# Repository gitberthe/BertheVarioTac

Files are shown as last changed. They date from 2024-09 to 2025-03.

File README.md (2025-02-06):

# Projet BertheVarioTac ESP32-2432S028
Projet d'alti vario gps parapente tactile (avec gestion des TMA CTR..., et mode guidage sol pour randonnée).
- Compatible bluetooth / XCTrack si nécessaire.
- Code C++ Visual Studio/PlateformIO.
- Plateforme Espressif ESP32 Dev Module, 2.8inch ESP32-2432S028, Arduino, ESP32-WROOM-32,  (processeur LX6 32bits, bi-core 240mhz).


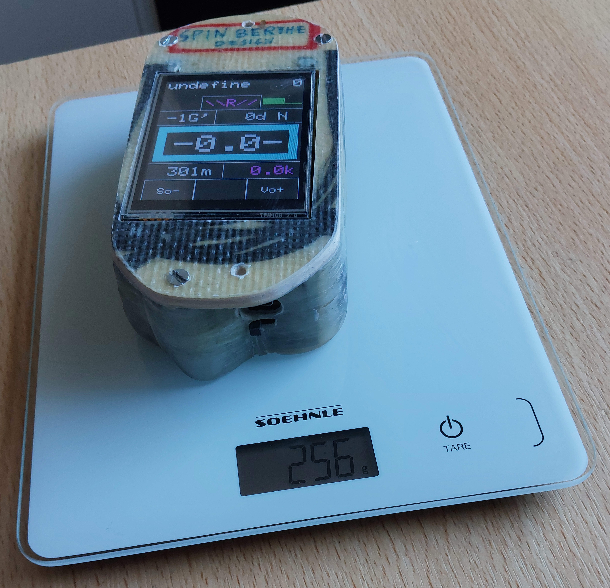
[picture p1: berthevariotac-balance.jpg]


**Utilisation / description :**
- documentation utilisateur et autre dans /documentation
- projet PlateformIO dans /BertheVarioTacPlatformIO
- editer/modifier avec codeblocks dans /Codeblocks
- documentation developpeur dans ../../DoxyBertheVarioTac avec le commande "doxygen Doxyfile.BertheVarioTac" depuis /Codeblocks

**Pour les développeur :**
- voir la documentation doxygen generée.

**Shemas dans /kicad-pcb :**

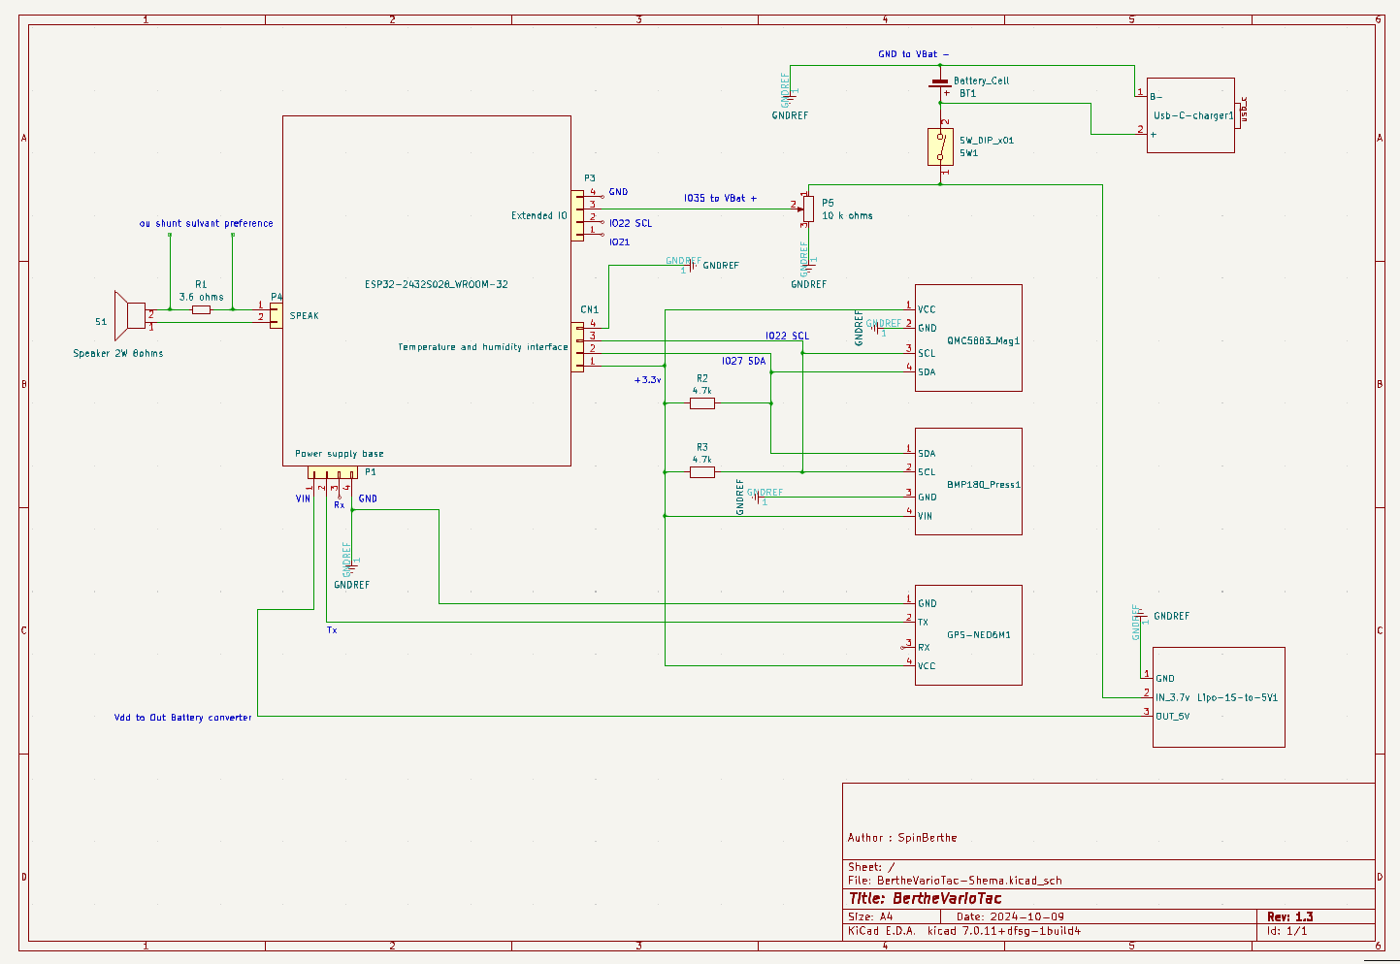
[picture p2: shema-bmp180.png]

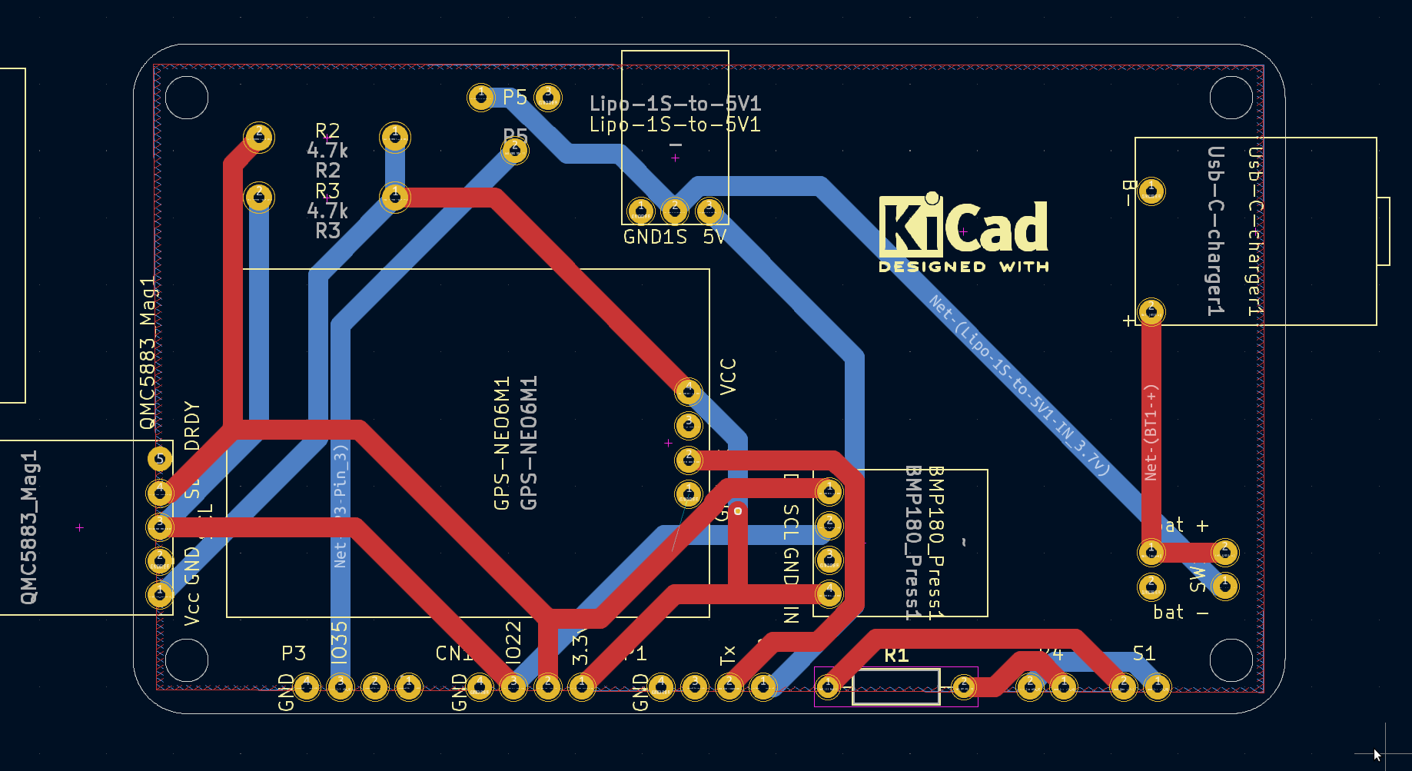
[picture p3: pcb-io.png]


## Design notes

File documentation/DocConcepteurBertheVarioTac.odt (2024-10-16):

Documentation Concepteur BertheVarioTac

Projet d’alti vario gps parapente

à base de 2.8inch ESP32-2432S028

Version : 2024091016b

https://github.com/gitberthe/BertheVarioTac

Compilé avec Visual Studio Code / PlatformIO

Espressif Systems

ESP32 Dev Module

ESP32-2432S028 Arduino

Wroom 32

langage C++.

# Mise en place de l’environnement logiciel :

Le logiciel est compilé avec Visual Studio Code / PlatformIO. Après l’ouverture du projet et téléchargement automatique des librairies, il faut décompresser 2.8inch_ESP32-2432S028R.rar.

* Copier alors le fichier 2.8inch_ESP32-2432S028R/1-Demo/Demo_Arduino/7_1_Touch_button_ILI9341_LovyanGFX/TFT_eSPI bottom layer replacement file/User_Setup.h ou ./src/Screen/User_Setup.h dans BertheVarioTacPlatformIO/.pio/libdeps/esp32dev/TFT_eSPI/User_Setup.h.

* De même, il faut copier BertheVarioTacPlatformIO/.pio/libdeps/esp32dev/LovyanGFX/examples/Advanced/LVGL_PlatformIO/src/lv_conf.h dans ./src/Screen/lv_conf.h

* La librairie pour le gestionnaire de fichier Wifi doit etre modifiée.

Dans BertheVarioTacPlatformIO/.pio/libdeps/esp32dev/ESP32 File Manager for Generation Klick ESPFMfGK/src/ESPFMfGKGa.cpp" ligne 6 : crc32.h => CRC32.h

La compilation du logiciel peut alors s’effectuer.

# Calibration de l’écran :

Il faut obtenir 8 paramètres de calibration de l’écran. Pour cela dans src/Screen/CLGFX.cpp dé-commenter la portion adéquate dans CLGFX::InitScreen() (ligne 81) pour récupérer sur le port série de PlatformIO les 8 paramètres à recopier par la suite dans le tableau de calibration calData[] (ligne 78). On a ainsi les bonnes coordonnées XY d’un point appuyé.

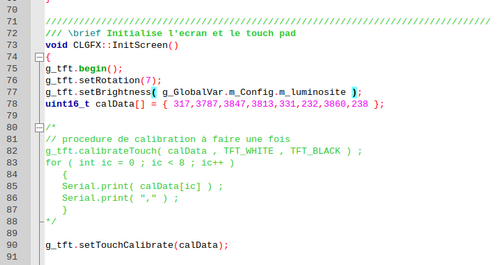
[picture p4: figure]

A noter que l’éclairage de l’écran perturbe grandement la mesure de luminosité (à isoler donc).

# Connexion Gps GY-NEO6MV2 :

If faut alimenter correctement le module par le connecteur CN1 en 3,3v. De même connecter la broche Tx du gps à la broche Tx du connecteur P1.

(la broche la broche IO35 du connecteur P3 est ainsi libre).

Attention, l’utilisation du Gps peut poser problème en mode débogage pour utiliser la liaison série usb de PlatformIO.

# Connexion capteur de pression BMP180 ou MS5611 :

If faut alimenter correctement le module par le connecteur CN1 en 3,3v. De même connecter la broche SDA à l’entrée 27 du connecteur CN1. Et la broche SCL à la pin 22 du connecteur P3 pour les ESP32-2432S028R ou à la broche NC/IO22 du connecteur CN1 pour les ESP32-2432S028.

# Connexion capteur magnétique QMC5883 :

If faut alimenter correctement le module par le connecteur CN1 en 3,3v. De même connecter la broche SDA à l’entrée 27 du connecteur CN1. Et la broche SCL à la pin 22 du connecteur P3 ou CN1. Capteur en parallèle sur le bus I2C avec le capteur de pression.

Ne pas oubliez de faire la calibration logicielle du capteur magnétique pour son bon fonctionnement (voir documentation utilisateur). Pour le boîtier, je vais essayer de mettre le câblage et le haut parleur le plus loin de ce capteur.

# Connexion de la batterie :

Connecter la batterie à la pin IO35 de la prise P3, par l’intermédiaire d’un potentiomètre de 10k ohms. Que l’on réglera pour avoir la bonne tension affichée.

# Alimentation :

Connecter la batterie 4,2v 1S lipo 2000 mah à la broche Vin de P1 par l’intermédiaire du convertisseur DC-DC 3,7v / 5V. Connecter la batterie au chargeur Usb C.

# haut parleur :

Connecter le haut parleur à la prise P4 par l’intermédiaire d’un résistance de votre choix ou un shunt pour un très fort volume (haut parleur 2W 8 ohms + résistance 3,6 ohms dans mon cas) .

# Utilisation du PCB :

Depuis la versions 20241010a un pcb est disponible. Connecter les différentes prises sur ce pcb. (prises JST 1.25) (à valider)

# Téléchargement du firmware :

Pour télécharger le firmware il y a 2 façons :

- soit par câble usb avec platformio ou un autre logiciel.

- soit par wifi. Il faut alors mettre le vario en mode téléchargement Fir en bas à droite de la page Sys. Et dé-commenter dans platformio.ini les lignes :

; extra_scripts = platformio_upload.py

; upload_protocol = custom

; upload_url = http://192.168.148.237

Avec bien sur l’adresse ip de l’url donnée par l’écran du BertheVarioTac. Cette procédure ne peut toutefois pas être faite au premier téléchargement de la carte ESP-2432S028 (R). Le logiciel ne s’y trouvant pas, il faut appliquer la procédure USB.

# Quelques photos :

Le câblage sur plaquette sans alimentation avec capteur MS5611 :

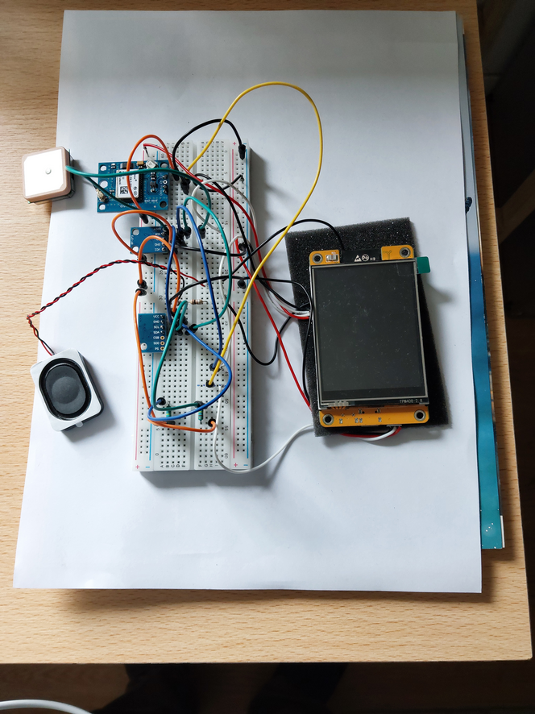
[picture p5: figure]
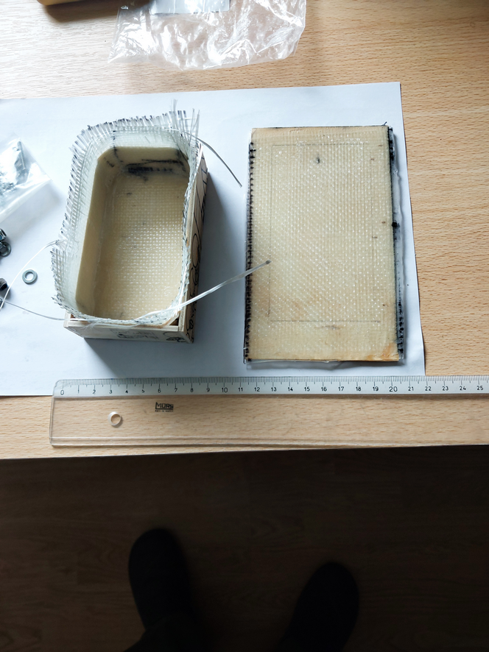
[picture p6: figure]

Les premiers pas du boîtier fibre époxy :

Les composants de la partie alimentation (testés sur la carte seule) :

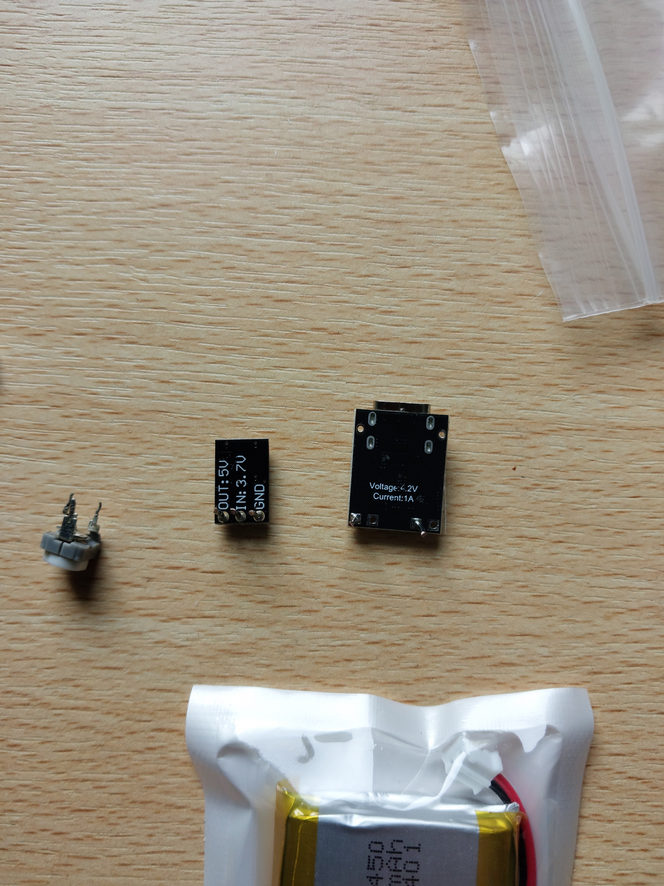
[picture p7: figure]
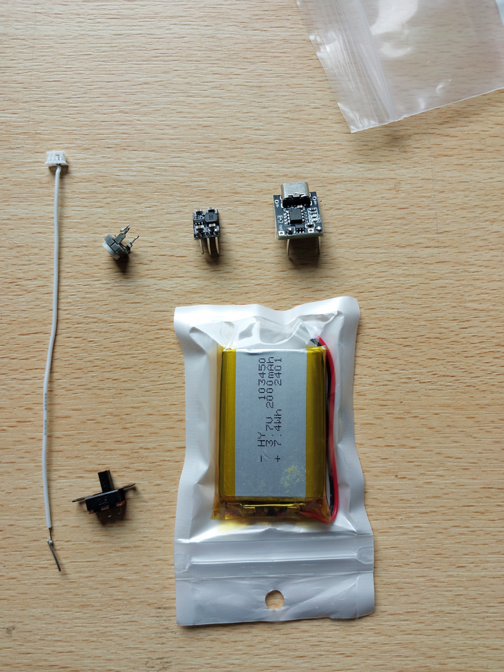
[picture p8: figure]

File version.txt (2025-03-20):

le 20250320a :
 - prise en compte de la hauteur sol pour pre-alarme frontiere XY à Saint-Sandoux.
 - emmission message xc_track determiné uniquement par #define XC_TRACK 
 - son vario toujours determiné par [xc_track] == 0 
 - declenchement debut de vol par 2 Vz minimales consecutives. 

le 20250301a :
 - meilleur prise en compte zone st-yan
 
le 20250225b :
 - modif plantage si mauvais zonesper.txt.

le 20250225a :
 - bug periodes tma st-yan. 

le 20250213a2 :
 - version documentation.

le 20250213a :
 - Modification de CZoneAer.
 - prise en compte de la hauteur sol pour la marge altitude zone à Corent.

le 20250210a :
   - ihm ligne vide si pas de zone TMA/CTR proche alti <=500m et dist <=999m.
   
le 20250209b :
 - remise a true des beep alarme zone, au debut du vol, lors desactivation
   attente gps.

le 20250209a :
 - apparition conditionnelle de l'altitude proche <500m et distance proche <= 999m.
   ex : _________ ou 455A _____ ou _____ 687NE ou 499A 999SE.
 - modification de CDistFront::IsNearFront().

le 20250208a :
 - alternance affichage terrain proche/finesse avec altitude/distance/cap 
   jusqu'a la prochaine zone TMA/CTR... rencontrée, à l'altitude ou l'on est,
   en metres. 999m maximum.
 - penetration zone TMA activement testeé à clermont. altitude/distance/cap zone 
   proche moin testé.

le 20250207c :
 - corection fuite memoire ~CZoneAer(). Meilleur fonctionnement fileManager.

le 20250207b :
 - correction bug important zone activable masquée par zone avec derogation.

le 20250207a :
 - gain memoire wifi ota bluetooth.
 - correction bug CDistFront::IsNearFront() vecteurs colineaire.

le 20250206a :
 - calcul penetration zone et terrain proche à 2hz.

le 20250204a :
 - menu deroulant mode rando.
 - ajout de #define XC_TRACK dans BertheVarioTac.h pour eviter une consommation memoire si inutilise.
 
le 20250203a :
 - modification initialisation hauteur sol zone protegée fonction de la denomination 
    (variable et plus 1000/500/300/150/50m ex: "PROTECT reserve annecy 200m/sol")

le 20250130a :
 - ajout de [xc_track] pour envoi de la pression par bluetooth à XC-Track.

le 20250129a :
 - platform https://github.com/tasmota/platform-espressif32/releases/download/2024.12.30/platform-espressif32.zip
 - CSoundSvr changé.

le 20250125c :
 - page tma dessous, enregistrement point gps dans fichier terconnu.txt.
 
le 20250125b :
 - gestion de la luminosite de l'ecran differente au sol.
 - [lum_seconde] à la place de [luminosite] dans fichier de config.

le 20250125a :
 - offset temperature a froid.
 - Modification tma activation/desactivation.

le 20250124c :
 - screen epd text.

le 20250124b :
 - ecran histo en minutes decimale.
 - alarme sonore reculade.
 - alarme sonore frontiere zone et limite altitude.
 - son zerotage.
 - [alarme_reculade] dans fichier de config.
 - zone protege mieux determine

le 20250124a :
 - correction pt-decollage menu rando
 - confirmation reboot info/rando.
 - [coef_filtre_alti_baro] à 0.85 par defaut.
 
le 20250123a2 :
 - mise a jour documentation utilisateur.

le 20250123a :
 - mode rando utilisable.
 
le 20250122c :
 - modification doc concepteur.
 - ebauche mode rando.

le 20250122b :
 - update de librairie.
 - ebauche mode rando.

le 20250122a :
 - ajout affichage tma hauteur sol pour zone protect.
 - mise en conformite/import BertheVario
  . tache gps
  . tache son
  . temps de vol en float
  . [vz_igc_ms] à 0,5 par défaut.
  . [vitesse_igc_kmh] à 14 par defaut.
  - modification GetAltiMetres(). Plus de reset m_DiffAltiFchAgl.

le 20250121a :
 - mise a jour doc concepteur.
 - ajout d'un fichier de modif BertheVario à importer dans BertheVarioTac.

le 20241209a :
 - CompZoneAerienne.exe windows 10, zonesaer.txt inchangé.

le 20241205a :
 - structuration CompZoneAerienne, zonesaer.txt inchangé.
 
le 20241204a :
 - bug zone meme nom dans CompZoneAerienne. zonesaer.txt nouveau.
 
le 20241203a :
 - Gain memoire nom de CZoneAer string => char*.
 
le 20241202c :
 - Gain memoire doublon nom de CZoneAer.
 
le 20241202b :
 - Modification buffer de points CZoneAer.
 
le 20241202a :
 - Modification affichage CompZoneAerienne.
 - Modification determination zone protegee CZoneAer.
 - [coef_filtre_alti_baro] à 0,9 par défaut.

le 20241201d :
 - resolution variable dans la compression de zone en short firmware.
   resolution entiere de 1 à 7 metres pour les zones en presence, 1.95metre en moyenne.

le 20241201c :
 - simplification calcul dans zone et modification fichier de validation zone.

le 20241201b :
 - calcul rayon maxi/resolution mini zone dans CompZoneAerienne.
 - Modification resolution compression zone à 10. metres.

le 20241201a2 :
 - bug ligne de commande vide CompZoneAerienne.
 
le 20241201a :
 - correction calcul erreur moyenne pour CompZoneAerienne.
 - CompZoneAerienne genere les zones à partir de terconnu.txt.
 - modification buffer calcul zone pour zone 1000 pts cevennes.
 - prise en compte hauteur sol zone protege 1000/500/300/150/50m.
 
le 20241130c :
 - correction calcul erreur moyenne pour CompZoneAerienne.
 
le 20241130b :
 - augmentation des decimales et precision dans zonesaer.txt.

le 20241130a :
 - Erreur moyenne des courbes pour CompZoneAerienne.

le 20241129b :
 - enfin beton sur CompZoneAerienne et zonesaer.txt. Compression
   iterative 3 points distance droite < 4.5m. 
 - la resolution firmware des zones reste à 18m.

le 20241129a :
 - essai algorithme CompZoneAerienne.
 - zonesaer.txt inchangé.
 - CompZoneAerienne.exe Windows 10.
 
le 20241128d :
 - reorganisation fichier/commentaires CompZoneAerienne.
 
le 20241128c :
 - modification CompZoneAerienne, reduction zone par droite proche 
   de nuage de points.
 
le 20241128b :
 - mise a jour documentation.

le 20241128a :
 - CompZoneAerienne.exe Windows 10 avec ses dll.
 
le 20241127a :
 - modification BVTZoneAerienne en CompZoneAerienne.
 - deplacement de CVecZoneReduce.h/cpp.
 - l'algorithme de CompZoneAerienne de reduction de zone est desormais la 
   distance à la droite < 7 metres, distance entre points < 40 metres et
   angle entre points < 5 degres.

le 20241126d :
 - ota en pointeur.

le 20241126c :
 - verification si compression lz4 efficace.
 
le 20241126b :
 - correction bug fuite memoire decompression zone.

le 20241126a :
 - modification dans Screen/lv_conf.h

le 20241125c2 :
 - modification doc utilisateur.

le 20241125c :
 - ajout de la compression des float 32 bit en short 16 bits pour les CZoneAer.
   Resolution de 18m et zone imperativement dans le cercle de rayon 589km (sinon reboot)
 - ajout de compression lz4 pour tableau des short 16bits de CZoneAer.

le 20241125b :
 - la creation du fichier de zone aeriennes se fait desormais avec BVTZoneAerienne.
 - la reduction du nombre de points de zone ce fait desormais dans BVTZoneAerienne.
 - dans BVTZoneAerienne 2 methodes de reduction de zone, par distance entre points
   de 50 metres, et angle plat de 6 degres.
 - format de zonesaer.txt inchangé.
 
le 20241125a :
 - modification Screen/lv_conf.h
 - modification CText2Screen
 - modification CDate
 
le 20241124a :
 - modification methode calcul Vz.
 - [sat_sec] à 12 par défaut.
 - [vitesse_igc_kmh] à 16 km/h par défaut.
 - [coef_filtre_alti_baro] à 0,8 par défaut.
 - suppression [periode_integration_sec].

le 20241121a :
 - pose d'une batterie 4000mah modele 965068.

le 20241101c :
 - modification ihm.

le 20241101b :
 - optimisation affichage page Vz.
 - bug ecran/carte sd.

le 20241101a :
 - vbat max 4.25v pour barregraphe autonomie.
 - grosse amelioration temps de reponse ihm à 10 hz et consommation CPU.
 
le 20241030c4 :
 - vbat max 4.3v pour barregraphe autonomie.

le 20241030c3 :
 - abaissement frequences calcul et affichage pour eco energie.
 - abaissement frequences scan serveur de son pour eco energie.

le 20241030c2 :
 - luminosite = 1 pour plein soleil.
 - seuil jaune 40% barregraphe tension batterie.

le 20241030c :
 - taille barregraphe batterie.
 - de init wifi.
 - mode economie d'ebergie

le 20241030b :
 - changement luminosite division.
 - barregraphe tension batterie.

 le 20241030a2 :
 - changement OTA.

le 20241030a :
 - changement luminosite minumum/maximum.
 
le 20241026a2 :
 - ajout procedure de reglage potentiometre dans documentation concepteur.

le 20241026a :
 - changement luminosite maximum.
 - pile CFinDeVol passe à 12 secondes.
 - [sat_sec] 12s par defaut pour 4 satellites.
 
le 20241025b2 :
 - changement de batterie pour une 4000mah 124065.

le 20241025b :
 - memorisation cap si non present.

le 20241025a :
 - ecartement du pcb batterie.

le 20241023b :
 - ajout vbatt en premiere page.
 - fonctionnement sur batterie ok (charge ok).

le 20241023a :
 - photos en plus dans documentation concepteur.

le 20241021a :
 - suppression fichier documentation obsolete.

le 20241020a :
 - [sat_sec] 0 pour 30 satellites.

 le 20241019a :
 - [sat_sec] 11s par defaut pour 4 satellites, 0 pour 28 satellites.
 
le 20241017a :
 - modification fonction luminosite.

le 20241016b :
 - optimisation memoire (suppression de taches et reduction buffer/stack).

le 20241016a :
 - correction bug ecran par mutex.
 - prise en compte du capteur de luminosite (à isoler des led de l'ecran).

le 20241015a :
 - [sat-sec] passe à 10s par defaut.

le 20241014a :
 - telechargement firmware par wifi ok.

le 20241012b :
 - validation capteur MS5611.

le 20241012a :
 - [temps_igc_sec] passe à 3s par defaut.
 - Vz declenclement de vol pendant [temps_igc_sec].
 - [sat_sec] 9s par defaut pour 4 satellites (puis 0s pour 26 satellites).
 - correction bug editeur cfg file.
 
le 20241010b :
 - essai mesure luminosite.

le 20241010a :
 - mise à jour documentation utilisateur et concepteur.
 - ajout numero de firmware en page sys.
 - pcb en commande.

le 20241009b :
 - ajout resistances Sda Scl pcb.

le 20241009a :
 - purge des boutons non bloquant.

le 20241008a :
 - [vz_igc_ms] pendant 3s pour déclenchement de vol.
 - modification pcb.

le 20241007b :
 - intergation logiciel pour capteur de pression MS5611 plus precis.

le 20241007a :
 - pcb a tester, compatible MS5611.

le 20241006a :
 - essai pcb.

le 20241005d :
 - modification conditions "EnVol".

le 20241005c :
 - doc utilisateur et modification code.
 
le 20241005b :
 - correction bug reboot systematique en wifi.

le 20241005a :
 - fonctionnement capteur magnetique ok.

le 20241003a :
 - fonctionnement gps + baro + son ok.

le 20241002a :
 - optimisation memoire globale;
 
le 20240928a :
 - correction bug zone limite alti XY

 le 20240927b :
 - modification zone limite alti XY

le 20240927a :
 - modification IHM zones hgt.

le 20240926a :
 - shema electrique kicad.
 - refonte ihm.

le 20240925c :
 - ihm selection de pages.

le 20240925b :
 - optimization int/long.
 
le 20240925a :
 - refonte calcul zones aeriennes.

le 20240924b :
le 20240924a :
 - modification IHM.

le 20240923c :
 - mesure de tension ok.

le 20240923a :
 - Wifi ok.
 
le 20240922b :
 - ok pages ihm sans bug carte SD.

le 20240921a :
 - trame gps fonctionnelle avec carte SD.
 
le 20240921a :
 - reorganisation CScreen

le 20240920a :
 - debut du projet BertheVarioTac

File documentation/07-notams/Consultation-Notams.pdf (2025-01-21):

# Site du Service de l’Information Aéronautique (SIA)

## Consultation des Notams

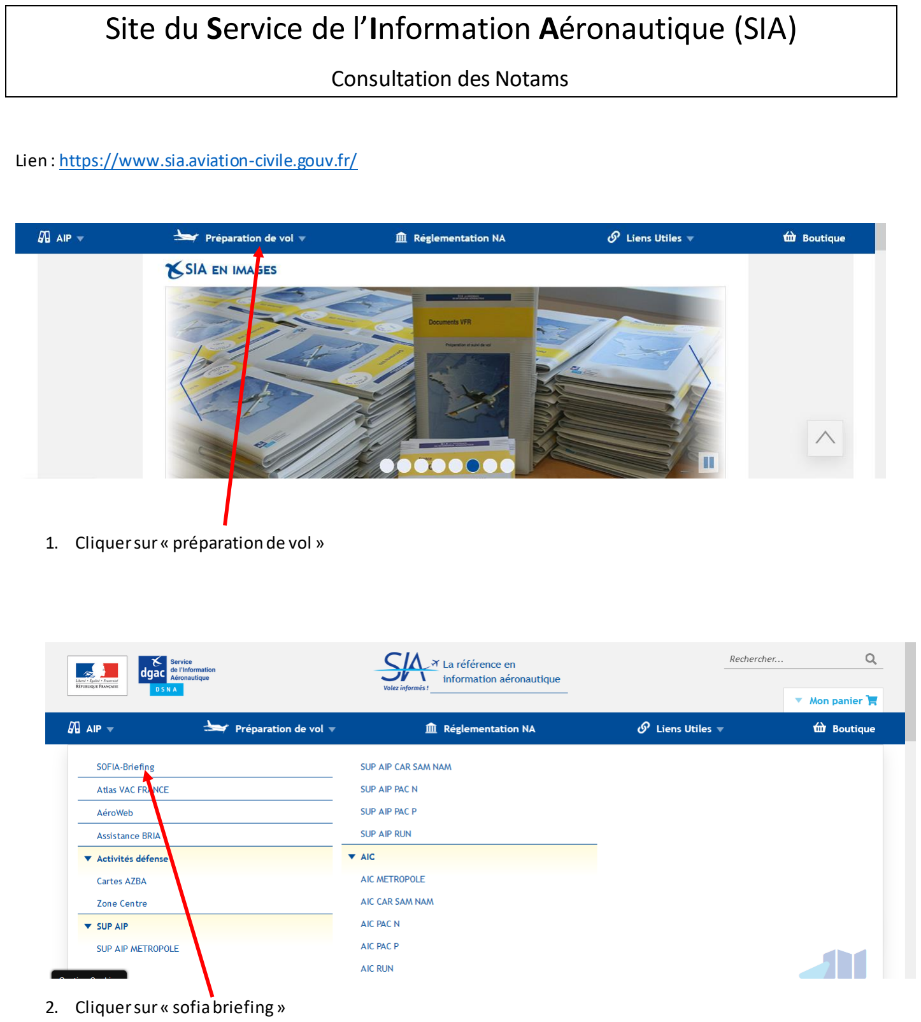
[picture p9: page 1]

Lien : https://www.sia.aviation-civile.gouv.fr/

1. Cliquer sur « préparation de vol »
2. Cliquer sur « sofiabriefing »

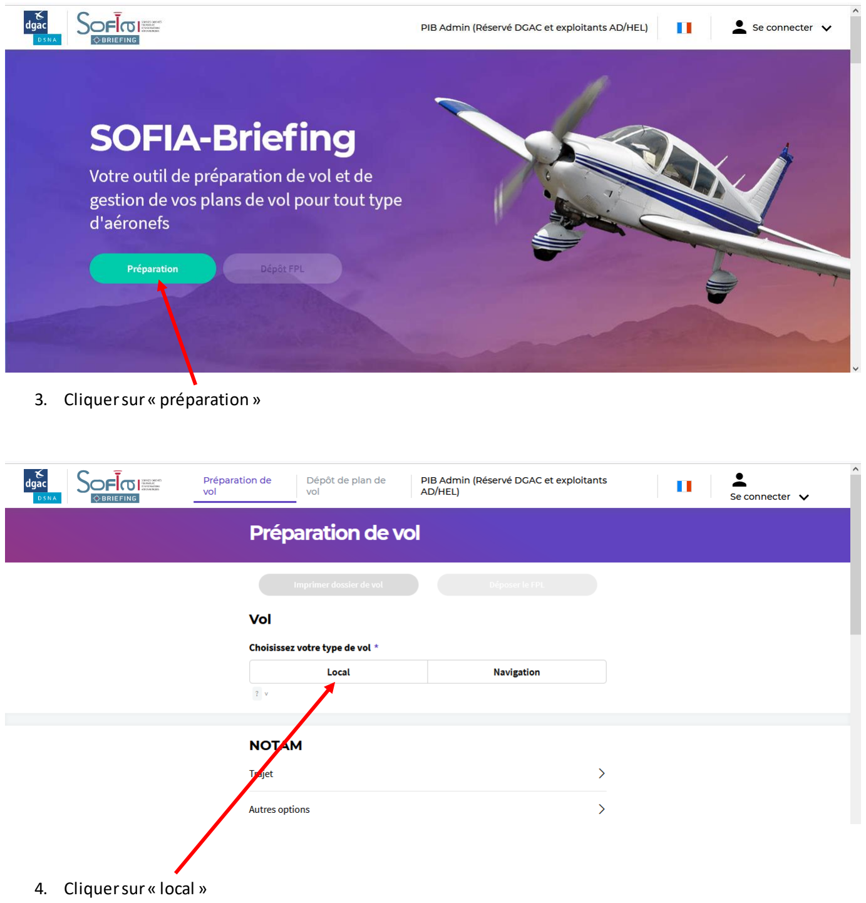
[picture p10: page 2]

3. Cliquer sur « préparation »
4. Cliquer sur « local »

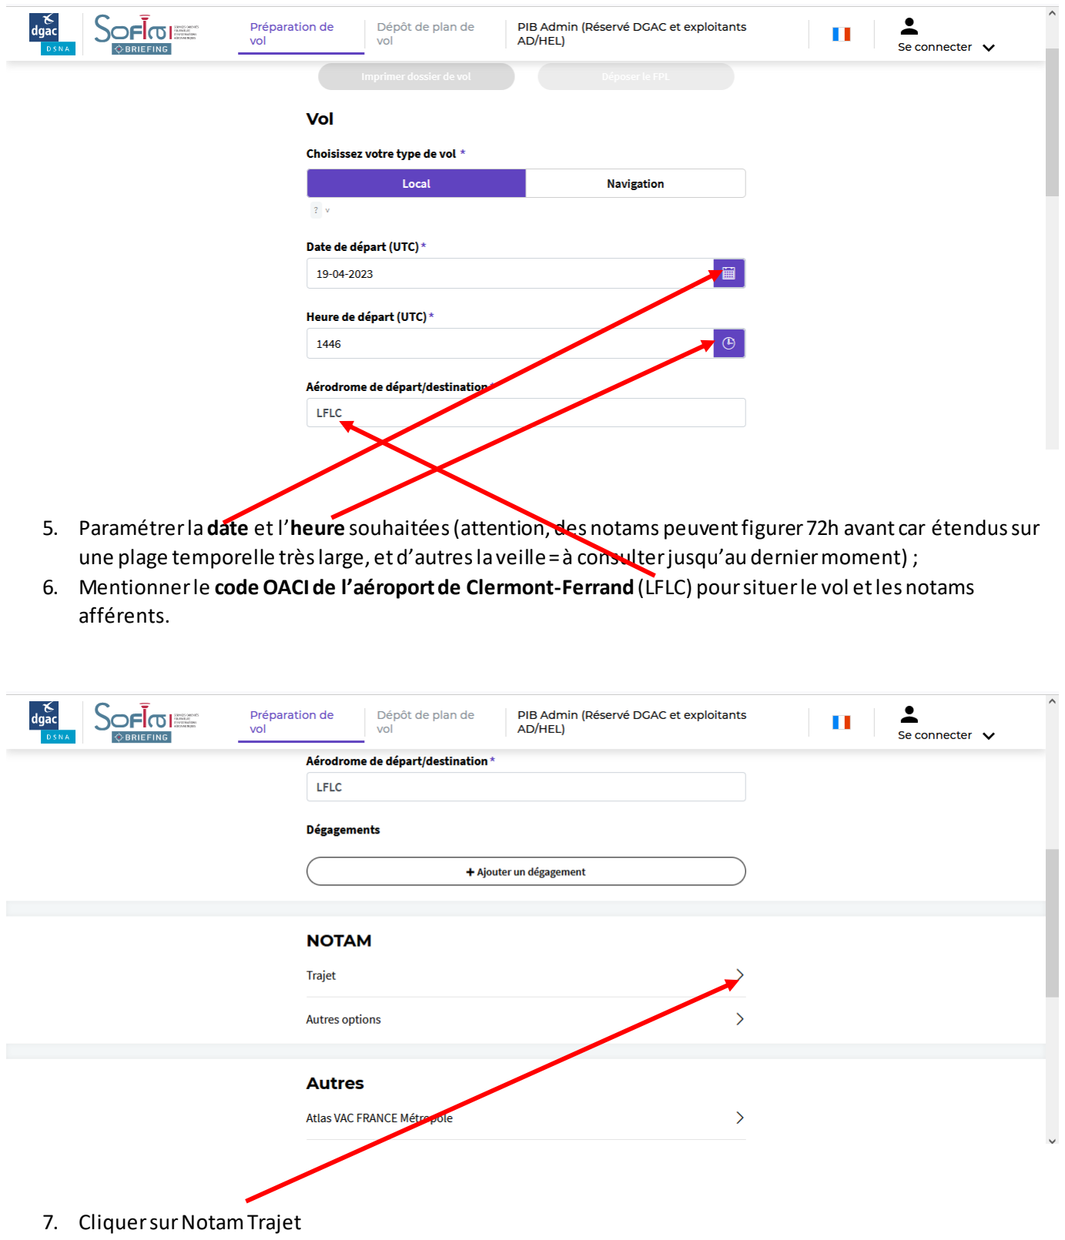
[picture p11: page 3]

5. Paramétrer la date et l’heure souhaitées(attention, des notams peuvent figurer 72h avant car étendus sur une plage temporelle très large, et d’autres la veille = à consulter jusqu’au dernier moment) ;
6. Mentionner le code OACI de l’aéroport de Clermont-Ferrand (LFLC) pour situer le vol et les notams afférents.
7. Cliquer sur Notam Trajet

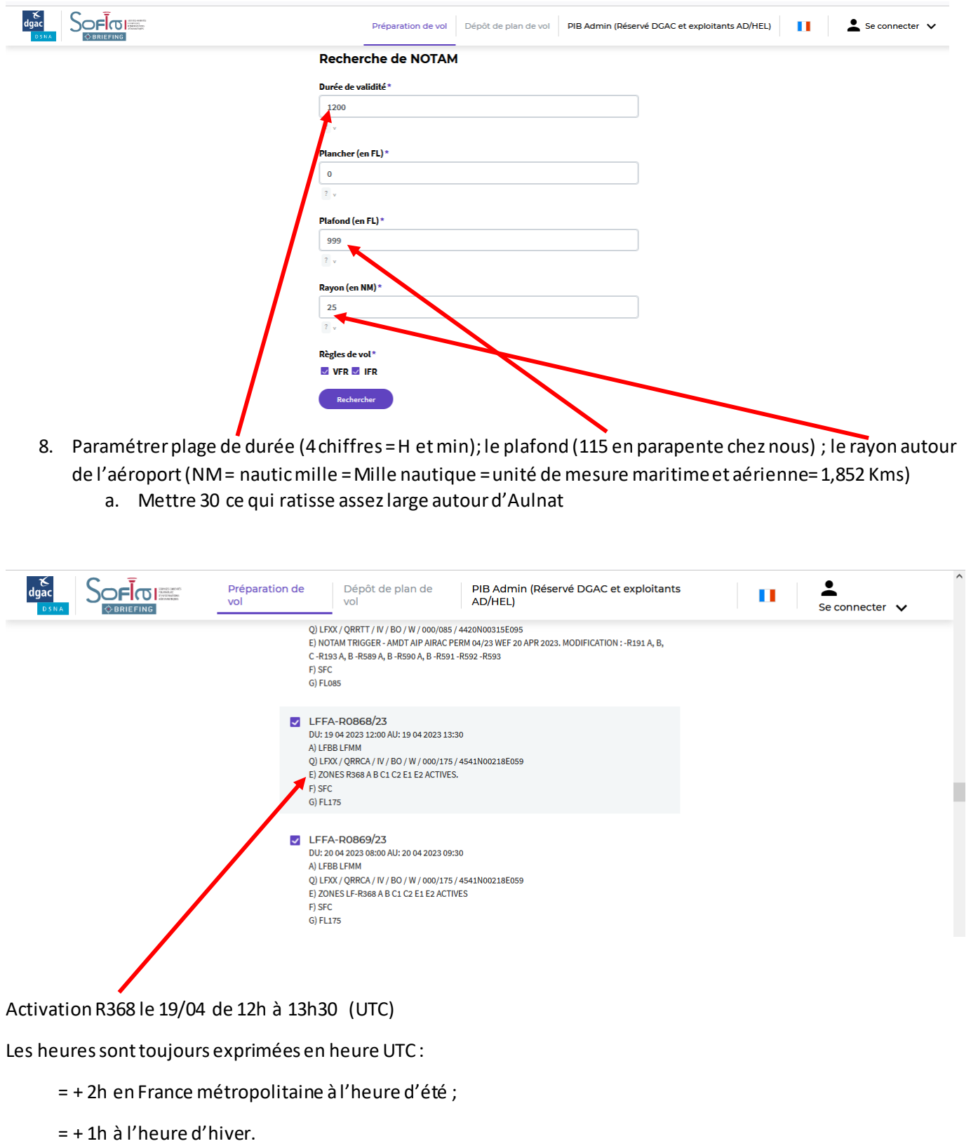
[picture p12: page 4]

8. Paramétrer plage de durée (4 chiffres = H et min); le plafond (115 en parapente chez nous) ; le rayon autour de l’aéroport(NM = nautic mille = Mille nautique = unité de mesure maritime et aérienne= 1,852 Kms)
a. Mettre 30 ce qui ratisse assez large autour d’Aulnat

Activation R368 le 19/04 de 12h à 13h30 (UTC)

Les heures sont toujours exprimées en heure UTC :

= + 2h en France métropolitaine à l’heure d’été ;

= + 1h à l’heure d’hiver.

## Décrypter un NOTAM

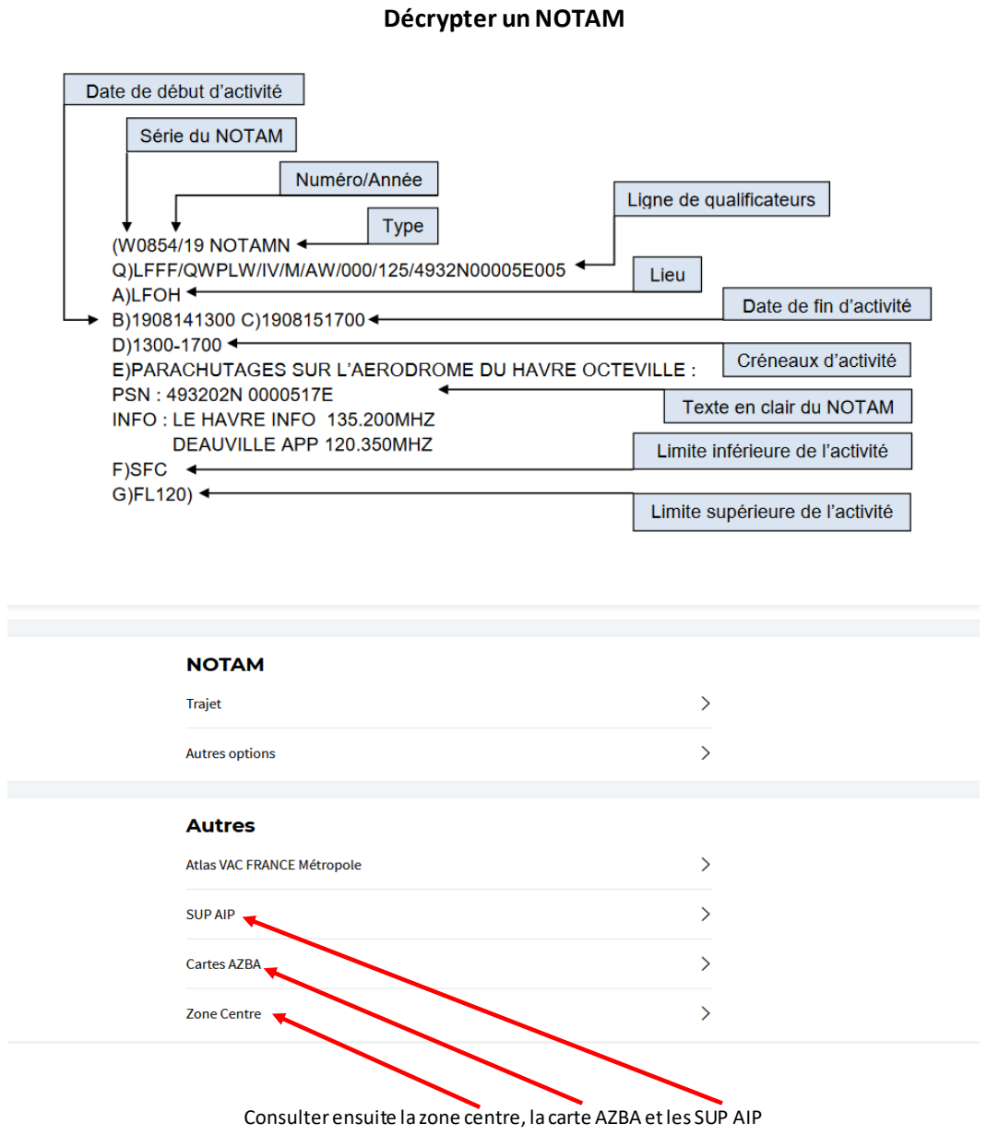
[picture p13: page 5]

Consulter ensuite la zone centre, la carte AZBA et les SUP AIP

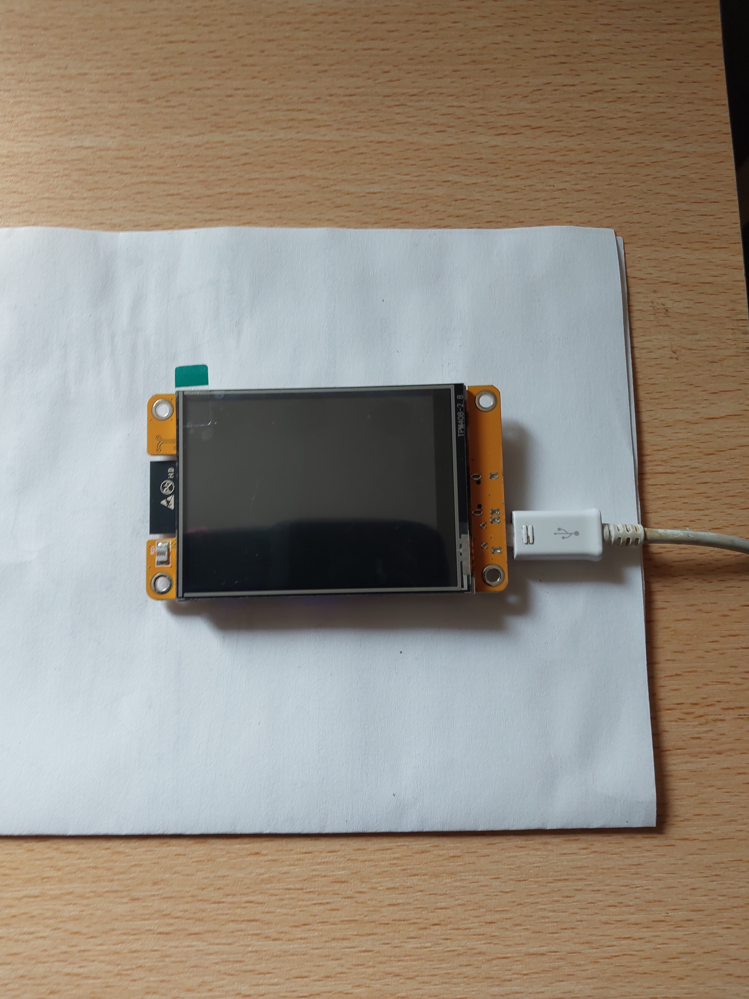
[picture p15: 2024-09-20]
ESP32-2432S028.jpg

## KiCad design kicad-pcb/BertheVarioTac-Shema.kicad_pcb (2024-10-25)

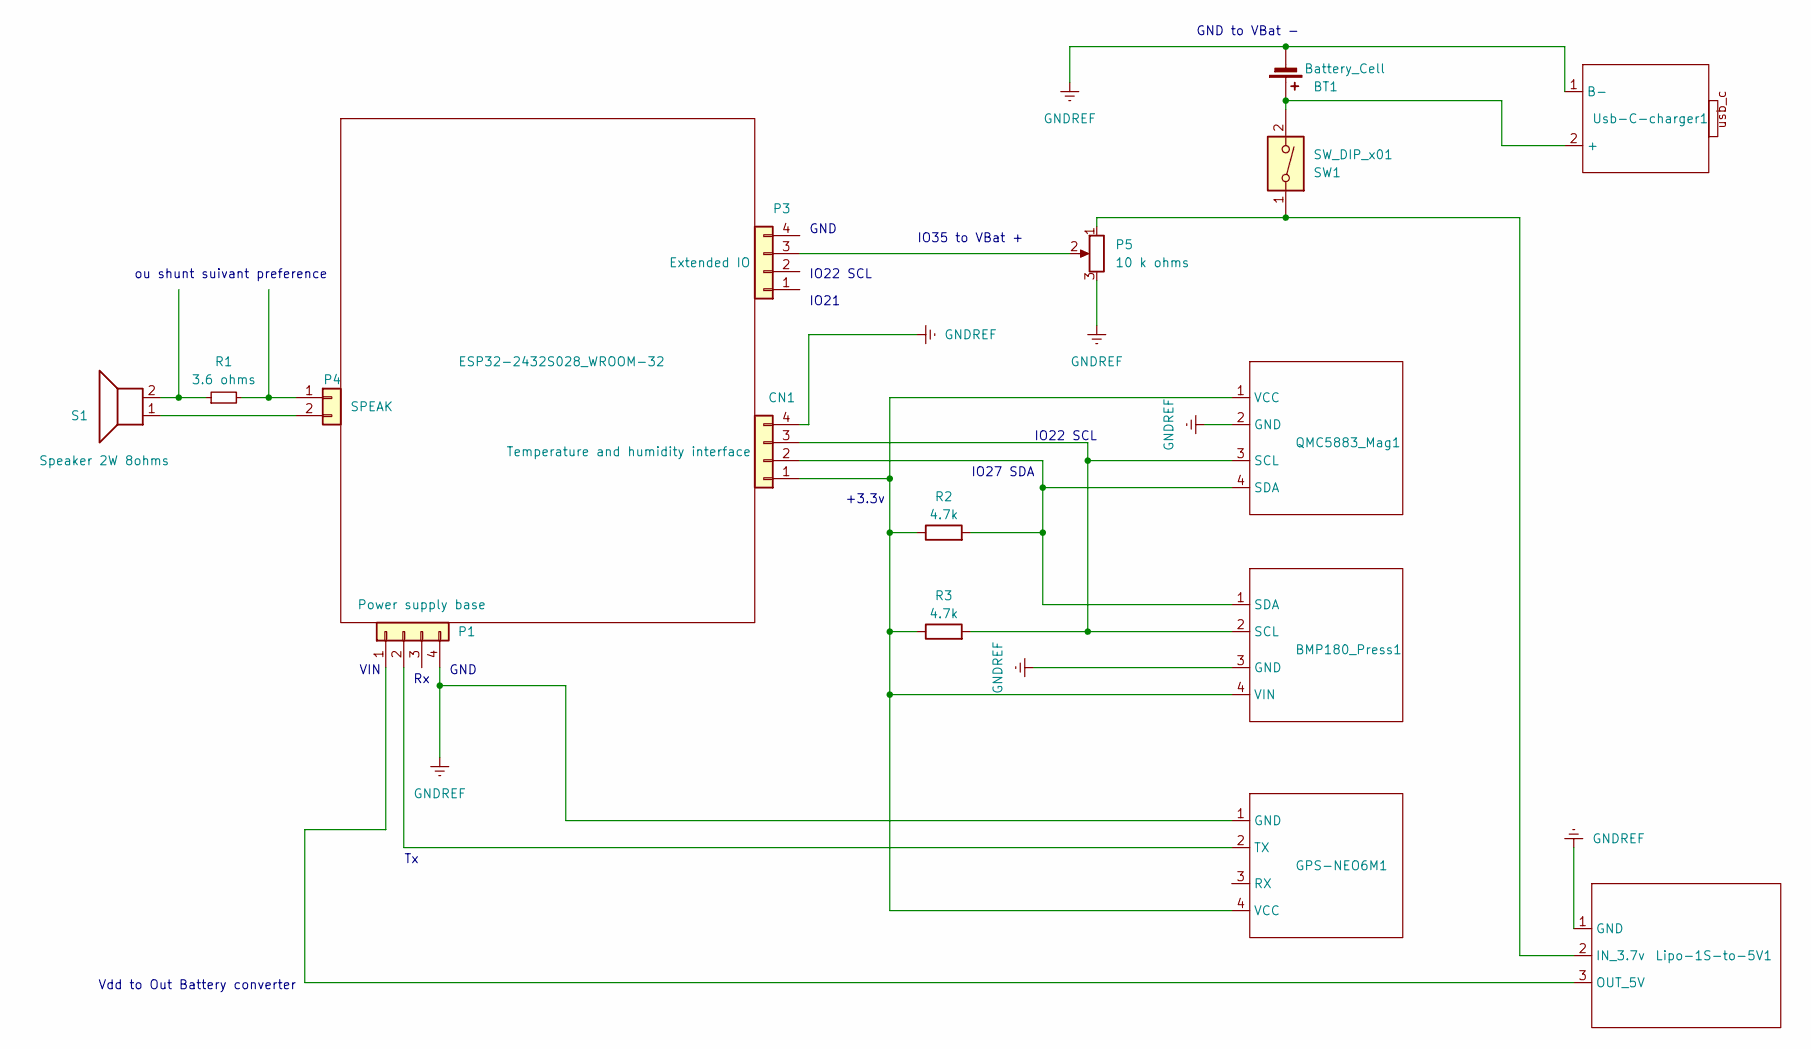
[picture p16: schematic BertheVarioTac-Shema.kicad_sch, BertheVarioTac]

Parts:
BMP180_Press1: BMP180
BT1: Battery_Cell; batterie
CN1: Temperature and humidity interface; 4 trous standard
ESP32-2432S028_WROOM-32: -; KiCad-Logo2_5mm_SilkScreen
GPS-NEO6M1: -; GPSNEO6V2
Lipo-1S-to-5V1: -; 1S-to-5v
P1: Power supply base; 4 trous standard
P3: Extended IO; 4 trous standard
P4: SPEAK; 2 trous standard
P5: 10 k ohms; potentiometre
QMC5883_Mag1: QMC5883
R1: 3.6 ohms; R_Axial_DIN0207_L6.3mm_D2.5mm_P10.16mm_Horizontal
R2, R3: 4.7k; R_47
S1: Speaker 2W 8ohms; 2 trous standard
SW1: SW_DIP_x01; 2 trous standard
Usb-C-charger1: -; Usb-C-Charger

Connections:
GNDREF: BMP180_Press1.3 (GND), BT1.2 (-), CN1.4, GPS-NEO6M1.1 (GND), Lipo-1S-to-5V1.1 (GND), P1.4, P5.3, QMC5883_Mag1.2 (GND), Usb-C-charger1.1 (B-)
unnamed: BMP180_Press1.2 (SCL), CN1.3, QMC5883_Mag1.3 (SCL), R3.2
unnamed: BMP180_Press1.1 (SDA), CN1.2, QMC5883_Mag1.4 (SDA), R2.2
unnamed: BMP180_Press1.4 (VIN), CN1.1, GPS-NEO6M1.4 (VCC), QMC5883_Mag1.1 (VCC), R2.1, R3.1
unnamed: BT1.1 (+), SW1.2, Usb-C-charger1.2 (+)
unnamed: GPS-NEO6M1.2 (TX), P1.2
unnamed: Lipo-1S-to-5V1.2 (IN_3.7v), P5.1, SW1.1
unnamed: Lipo-1S-to-5V1.3 (OUT_5V), P1.1
unnamed: P3.3, P5.2
unnamed: P4.1, R1.2
unnamed: P4.2, S1.1
unnamed: R1.1, S1.2

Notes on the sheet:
IO22 SCL
Vdd to Out Battery converter
GND
GND to VBat -
IO27 SDA
IO21
IO35 to VBat +
+3.3v
VIN
ou shunt suivant preference

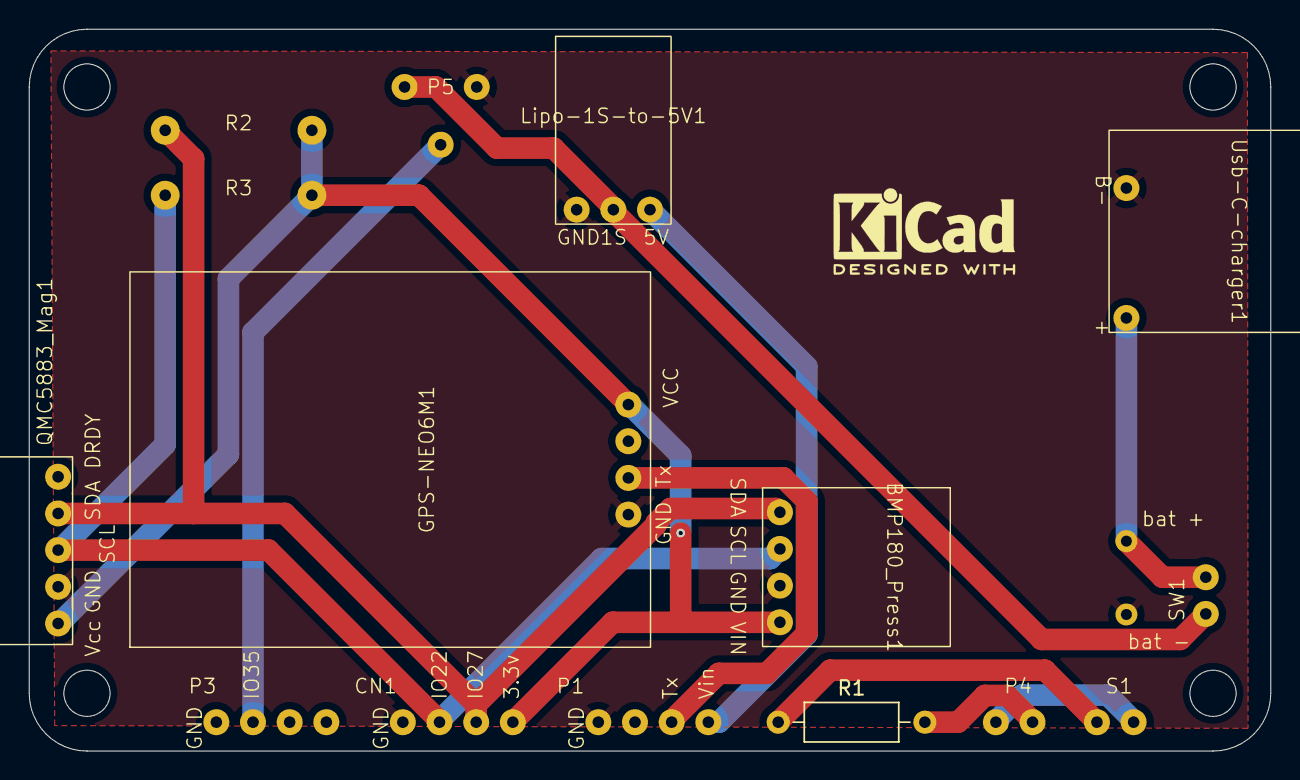
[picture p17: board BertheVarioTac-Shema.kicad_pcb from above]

Board: 2 copper layers, 86.0 x 50.0 mm, 17 parts (0 on the bottom side), 12 nets.

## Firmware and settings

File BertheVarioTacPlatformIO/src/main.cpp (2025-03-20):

////////////////////////////////////////////////////////////////////////////////
/// \file main.cpp
///
/// \brief loop de l'application
///
/// \date creation     : 21/09/2024
/// \date modification : 20/03/2025
///

#include "BertheVarioTac.h"

////////////////////////////////////////////////////////////////////////////////
/// \brief setup ESP32-2432S028
void setup()
{
//Serial.begin(115200);
#ifdef NO_GPS_DEBUG
 Serial.begin(9600);
 Serial.println("Debugage on" ) ;
#endif
//goto fin ;

// lancement tache son
g_GlobalVar.LanceTacheSound() ;
delay(500) ;
g_GlobalVar.BeepOk() ;
g_GlobalVar.beeper( SOUND_DELAY_ONLY , 100 ) ;
g_GlobalVar.BeepOk() ;

// tache de mise a jour % cpu
perfmon_start() ;

// init pin d'entree de tension
g_GlobalVar.InitBattery() ;

// initialisation de l'ecran tactile
g_tft.InitScreen() ;

// affaichage vbat
AfficheEcranDebut() ;

// init sdcard
g_GlobalVar.InitSDCard() ;

// Init BUS I2C
g_GlobalVar.InitI2C() ;

// lecture fichier terrains
g_GlobalVar.m_TerrainArr.LireFichierTerrains(TERRAIN_FCH) ;

// lecture fichier zones aeriennes
g_GlobalVar.m_ZonesAerAll.LectureFichiers() ;

// lecture fichier de configuration
g_GlobalVar.m_Config.LectureFichier() ;
g_GlobalVar.m_Config.FreeVect() ;

// init capteur de pression
g_GlobalVar.m_pCapteurPression->InitCapteur() ;

// init capteur magnetique
g_GlobalVar.m_QMC5883Mag.InitMagnetique() ;

#ifndef NO_GPS_DEBUG
 // init port serie GPS
 g_GlobalVar.InitGps() ;

 // lancement tache gps
 g_GlobalVar.LanceTacheGps(true) ;
#else
 g_GlobalVar.m_DureeVolMin = ATTENTE_MESSAGE_GPS ;
#endif // NO_GPS_DEBUG

// lancement tache beep
g_GlobalVar.LanceTacheVarioCapBeep() ;

// raz de l'ecran
g_GlobalVar.m_Screen.ScreenRaz(false) ;

// desactivation du wifi pour autonomie batterie
esp_wifi_stop() ;
esp_wifi_deinit() ;

// blue tooth
#ifdef XC_TRACK
 g_GlobalVar.m_BleXct.Init( BLE_NAME ) ;
#else
 esp_bt_controller_disable();
 esp_bt_controller_deinit();
#endif

// mode economie d'energie
esp_pm_config_esp32_t pm_config ;
pm_config.max_freq_mhz = 100; // 160 240
pm_config.min_freq_mhz = 40;
pm_config.light_sleep_enable = true ;
ESP_ERROR_CHECK(esp_pm_configure(&pm_config));
}


////////////////////////////////////////////////////////////////////////////////
/// \brief boucle sans fin
void loop()
{
// variables
static int count_10hz = 0 ;
static bool WifiSetupFileMgr = true ;
static bool WifiSetupOta = true ;

////////////////////////
// si mode wifi file mgr
if ( g_GlobalVar.m_ModeHttpFileMgr )
    {

    // si init wifi
    if ( WifiSetupFileMgr )
        {
        // init file manager
        WifiSetupFileMgr = false ;
        WifiInitFileMgr() ;
        }

    g_pfilemgr->handleClient();

    // si ecran pressé on reboot
    if ( !(count_10hz++%100) )
        {
        // traitement de touch pad
        g_GlobalVar.m_Screen.HandleTouchScreen() ;

        // scan les boutons tactiles
        g_GlobalVar.m_Screen.HandleButtons() ;

        if ( g_GlobalVar.m_Screen.IsCenterPressed() )
            g_GlobalVar.Reboot() ;
        }

    return ;
    }

////////////////////
// si mode wifi ota
if ( g_GlobalVar.m_ModeHttpOta )
    {
    // si init wifi
    if ( WifiSetupOta )
        {
        WifiSetupOta = false ;
        WifiInitOta() ;
        }

    WifiOtaHandle() ;

    // si ecran pressé on reboot
    if ( !(count_10hz++%100) )
        {
        // traitement de touch pad
        g_GlobalVar.m_Screen.HandleTouchScreen() ;

        // scan les boutons tactiles
        g_GlobalVar.m_Screen.HandleButtons() ;

        if ( g_GlobalVar.m_Screen.IsCenterPressed() )
            g_GlobalVar.Reboot() ;
        }

    return ;
    }

/////////////////
// ecran de debut
if( (millis()-g_GlobalVar.m_temps_debut)/1000 < 5 )
    {
    g_GlobalVar.m_Screen.m_MutexTft.PrendreMutex() ;
     AfficheEcranDebut() ;
    g_GlobalVar.m_Screen.m_MutexTft.RelacherMutex() ;
    delay( 1000 ) ;
    return ;
    }

////////
// 10 hz
unsigned long time = millis() ;

// traitement de touch pad
//g_GlobalVar.m_Screen.m_MutexTft.PrendreMutex() ;
 g_GlobalVar.m_Screen.HandleTouchScreen() ;
//g_GlobalVar.m_Screen.m_MutexTft.RelacherMutex() ;

// scan les boutons tactiles
g_GlobalVar.m_Screen.m_MutexTft.PrendreMutex() ;
 bool Action = g_GlobalVar.m_Screen.HandleButtons() ;
g_GlobalVar.m_Screen.m_MutexTft.RelacherMutex() ;

// affichage des boutons
g_GlobalVar.m_Screen.m_MutexTft.PrendreMutex() ;
g_tft.startWrite();
 g_GlobalVar.m_Screen.AfficheButtons() ;
g_tft.endWrite();
g_GlobalVar.m_Screen.m_MutexTft.RelacherMutex() ;

// compteur 10 hz
count_10hz++ ;

// 10 hz
while ( millis() - time < 100 )
    delay( 10 ) ;

// envoi bluetooth Xc-Track
#ifdef XC_TRACK
if ( g_GlobalVar.m_BleXct.IsInitialised() )
    g_GlobalVar.m_BleXct.Send() ;
#endif

///////
// 2 hz
if ( (count_10hz%5) && !Action )
    return ;

// si page Vz en cours
bool SpeedScreen = g_GlobalVar.m_Screen.GetEtatAuto() == CAutoPages::ECRAN_0_Vz ;

// affichage des pages
g_GlobalVar.m_Screen.m_MutexTft.PrendreMutex() ;
if ( SpeedScreen )
    g_tft.startWrite();
g_GlobalVar.m_Screen.SequencementPages() ;
if ( SpeedScreen )
    g_tft.endWrite();
g_GlobalVar.m_Screen.m_MutexTft.RelacherMutex() ;

// pour eviter mutex accet carte sd/ecran
if ( g_GlobalVar.m_Screen.GetEtatAuto() == CAutoPages::ECRAN_9b_RandoVolCarte )
    {
    CHgt2Agl Hgt2Agl ;
    g_GlobalVar.m_TerrainPosCur.m_AltiBaro = Hgt2Agl.GetGroundZ( g_GlobalVar.m_TerrainPosCur.m_Lon , g_GlobalVar.m_TerrainPosCur.m_Lat ) ;
    }

#ifdef NO_GPS_DEBUG
 static int count_debug = 0 ;
 Serial.print( count_debug++) ;
 Serial.println(" mode debug") ;
#endif


// calcul des zones aeriennes
g_GlobalVar.m_ZonesAerAll.CalcZone() ;

// calcul terrain le plus proche
g_GlobalVar.m_TerrainArr.CalcTerrainPlusProche() ;

// mode economie d'energie
//esp_light_sleep_start() ;

//tft.sleep() ;
//tft.powerSaveOn() ;
//g_tft.startWrite(); // bug avec carte SD si utilisation
//tft.beginTransaction();

// sequencement des pages
//g_GlobalVar.m_Screen.SequencementPages() ;

// raz de l'etat des boutons tactiles
//g_GlobalVar.m_Screen.RazButtons() ;

//g_tft.endWrite(); // bug avec carte SD si utilisation

//tft.clearClipRect()  ;
//tft.fillRect(0, 0,240,320,TFT_WHITE);
//tft.clearDisplay() ;
//tft.powerSaveOff() ;
//tft.wakeup() ;
//tft.endTransaction();

//uxTaskGetStackHighWaterMark(NULL) ;
}

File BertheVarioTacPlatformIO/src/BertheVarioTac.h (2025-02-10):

////////////////////////////////////////////////////////////////////////////////
/// \file BertheVarioTac.h
///
/// \brief Include global du projet de vario tactile
///
/// \date creation     : 20/09/2024
/// \date modification : 10/02/2025
///

//#define NO_OTA

//////////////////////
// includes globaux //
//////////////////////
#include <esp32-hal-i2c.h>
#include <esp32-hal-dac.h>
#include <Wire.h>
#include <Arduino.h>
#include <SPI.h>
#include <SD.h>
#include <WiFi.h>
#ifndef NO_OTA
 #include <WiFiClient.h>
 #include <WebServer.h>
 #include <HTTPClient.h>
 #include "esp_tls.h"
 #include "esp_http_client.h"
 #include "mbedtls/ssl.h"
 #include "ssl_client.h"
 #include "mqtt_client.h"
 #include "esp_tls.h"
 #include "esp_sntp.h"
#endif
#include <FS.h>
#include <ESPFMfGK.h>
#include <SFE_BMP180.h>
#include <MS5611.h>
#include <freertos/queue.h>
#include <soc/dac_channel.h>
#include <driver/dac.h>
#include <DFRobot_QMC5883.h>
#include <esp_wifi.h>
#include <esp_bt.h>
#include <esp_pm.h>
#include <lz4.h>
#include <NimBLEDevice.h>

#include <math.h>
#include <map>
#include <vector>
#include <algorithm>
#include <limits>

////////////////////////////////////////////////////////////////////////////////
// platform precedente
// bad : platform = espressif32
// bad : platform = https://github.com/pioarduino/platform-espressif32/releases/download/stable/platform-espressif32.zip
// bad : platform = https://github.com/platformio/platform-espressif32.git
// platform = https://github.com/tasmota/platform-espressif32/releases/download/2024.01.01/platform-espressif32.zip
// platform = https://github.com/tasmota/platform-espressif32/releases/download/2024.12.30/platform-espressif32.zip

//////////////////////////
// define pour le debug //
//////////////////////////
//#define GPS_DEBUG
//#define PERFMON_DEBUG
//#define NO_GPS_DEBUG
//#define MAG_DEBUG
//#define BRIGHT_DEBUG
//#define DEBUG_RANDO_VOL

/////////////////////////////
// define pour le materiel //
/////////////////////////////
//#define BMP180_PRESS
#define MS5611_PRESS
#define XC_TRACK

//////////////////////////
// includes du logiciel //
//////////////////////////
#include "GlobalVar/CMutex.h"
#include "Screen/CBrightness.h"
#include "Screen/CTouchButtons.h"
#include "Screen/CLGFX.h"
#include "Screen/CAutoPages.h"
#include "Screen/CText2Screen.h"
#include "Screen/CScreen.h"
#include "GlobalVar/CFileHistoVol.h"
#include "GlobalVar/CNbSatDelay.h"
#include "GlobalVar/CConfigFile.h"
#include "Calculateur/CSortArray.h"
#include "Calculateur/CTerrainsConnu.h"
#include "Calculateur/CFinSol.h"
#include "SDCard/CSDCard.h"
#include "Perfmon/esp32_perfmon.h"
#include "Geometrie/CVecteur2D.h"
#include "Geometrie/CDroite2D.h"
#include "Geometrie/CVecteur3D.h"
#include "Geometrie/CDroite3D.h"
#include "Geometrie/CMatrice3D.h"
#include "Geometrie/Segments.h"
#include "ZonesAeriennes/CDate.h"
#include "ZonesAeriennes/CZoneAer.h"
#include "ZonesAeriennes/CDistFront.h"
#include "ZonesAeriennes/CPolygone.h"
#include "ZonesAeriennes/CZonesAerAll.h"
#include "ZonesAeriennes/CZonesFchValid.h"
#include "Gps/CTrame.h"
#include "Gps/CIgc.h"
#include "Gps/CStabGps.h"
#include "Gps/CFinDeVol.h"
#include "Gps/CGps.h"
#include "Gps/CHgt2Agl.h"
#include "Gps/CPileVit.h"
#include "BMP180/CBMP180Pression.h"
#include "MS5611/CMS5611Pression.h"
#include "FileMgr/FileMgr.h"
#include "VarioCapBeep/CVarioCapBeep.h"
#include "VarioCapBeep/CSoundSvr.h"
#include "QMC5883L/CQMC5883Mag.h"
#include "RandoVol/CFileGpx.h"
#include "RandoVol/CRandoVol.h"
#include "Bluetooth/CBleXct.h"

//#include "Wifi/NetworkClientSecure.h"
//#include "Wifi/CWifiNotam.h"

////////////////////////
// definition des pin //
////////////////////////

// GPS
//#define pinGpsRXD  (27)
//#define pinGpsRXD  (21)
//#define pinGpsRXD  (35)
#define pinGpsRXD  (1)
#define pinGpsTXD  (-1)

#define VoltageInPin  (35)
#define BrightnessPin (34)

// SDCARD
#define SDCARD_CS_PIN   5
#define SDCARD_MOSI_PIN 23
#define SDCARD_MISO_PIN 19
#define SDCARD_SCK_PIN  18

// SDA SCL
#define VARIO_SDA_PIN 27
//#define VARIO_SDA_PIN 21
//#define VARIO_SDA_PIN 35
#define VARIO_SCL_PIN 22

// haut parleur
#define SPEAKER_PIN 26

////////////////
// constantes //
////////////////

#define T_PI                   (3.1415926535)
#define UnMileEnMetres         (1852.)
#define MilesParDegres         (60.)

///////////
// macro //
///////////

#define FABS(x)     fabsf(x)
#define SQRT(x)     sqrtf(x)
#define SIN(x)      sinf(x)
#define COS(x)      cosf(x)
#define ACOS(x)     acosf(x)
#define POW(x,y)    powf(x,y)
#define FMOD(x,y)   fmodf(x,y)
#define FLOOR(x)    floorf(x)
#define MODF(x,y)   modff(x,y)

#define MIN( a , b )   (((a)<(b)) ? (a) : (b))
#define MAX( a , b )   (((a)>(b)) ? (a) : (b))

///////////////////////////
// taches plus affichage //
///////////////////////////

// tache touch, basse priorite core 0 necessaire ou plantage
/*#define TOUCH_NUM_TASK       0
#define TOUCH_STACK_SIZE     3000
#define TOUCH_PRIORITY       5
#define TOUCH_CORE           0*/

/////////////////////////////////////////////
// taches plus temps reel                  //
// FreeRtOs utilise le core 0 a 75% a vide //
/////////////////////////////////////////////

// scan capteur et calcul Vz priorite tres haute non interruptible
#define VARIOCAP_NUM_TASK   0
#define VARIOCAP_STACK_SIZE 1500
#define VARIOCAP_PRIORITY   20
#define VARIOCAP_CORE       1

// son vario fonction Vz priorite moyenne
#define VARIOBEEP_NUM_TASK   1
#define VARIOBEEP_STACK_SIZE 1000
#define VARIOBEEP_PRIORITY   15
#define VARIOBEEP_CORE       1

// serveur de son, priorite moyenne
#define SOUNDSVR_NUM_TASK   2
#define SOUNDSVR_STACK_SIZE 1500
#define SOUNDSVR_PRIORITY   10
#define SOUNDSVR_CORE       1

// acquisition gps, priorite haute non interruptible
#define SERIAL_NUM_TASK         3
#define SERIAL_GPS_STACK_SIZE   2800
#define SERIAL_GPS_PRIORITY     19
#define SERIAL_GPS_CORE         1

// ecriture igc, priorite moyenne
#define IGC_NUM_TASK    4
#define IGC_STACK_SIZE  3000
#define IGC_PRIORITY    10
#define IGC_CORE        1

// temps de vol / histo, basse priorite
#define TEMPS_NUM_TASK   5
#define TEMPS_STACK_SIZE 3000
#define TEMPS_PRIORITY   5
#define TEMPS_CORE       1

// relance pour cause faux depart de vol, tache fugitive.
#define RELANCE_IGC_NUM_TASK   6
#define RELANCE_IGC_STACK_SIZE 3000
#define RELANCE_IGC_PRIORITY   0
#define RELANCE_IGC_CORE       1

// tache de mesure d'occupation des cores 0 et 1
#define PERF_MON_NUM_TASK   7
#define PERF_MON_STACK_SIZE 800
#define PERF_MON_PRIORITY   1
#define PERF_MON_CORE       1

// nombre total de taches
#define SIZE_TASK 8


//////////////////////////
// includes du logiciel //
//////////////////////////
#include "GlobalVar/CNumTaskArr.h"
#include "GlobalVar/CGlobalVar.h"


////////////////////////////
// fonctions et variables //
////////////////////////////
void AfficheEcranDebut() ;
void WifiInitFileMgr() ;
void WifiInitOta() ;
void WifiOtaHandle() ;
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

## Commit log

2024-09-22 gps et carte sd
    [config.txt]
2024-09-22 creation des pages ihm
2024-09-22 good pages ihm bug sd
    [BertheVarioTac.h, CFileHistoVol.cpp, main.cpp]
2024-09-25 ajout kicad
    [BertheVarioTac-Shema.kicad_pcb, BertheVarioTac-Shema.kicad_sch]
2024-09-25 kicad shema
    [BertheVarioTac-Shema.kicad_sch]
2024-09-25 mise a jour kicad
    [BertheVarioTac-Shema.kicad_sch]
2024-09-26 modification ihm
    [BertheVarioTac-Shema.kicad_sch]
2024-09-26 modification kicad
    [BertheVarioTac-Shema.kicad_sch]
2024-09-26 Delete ESP32-2432S028.jpg
    doublon
2024-09-28 bug zone limite alti XY
    [BertheVarioTac.h, main.cpp]
2024-10-03 premier essai gps+baro
    [BertheVarioTac-Shema.kicad_pcb, BertheVarioTac-Shema.kicad_sch]
2024-10-03 son + gps + baro ok
    [BertheVarioTac-Shema.kicad_sch]
2024-10-03 serveur de son
2024-10-04 anti-rebond bouton
    [BertheVarioTac-Shema.kicad_sch]
2024-10-05 capteur magnetique ok
    [BertheVarioTac-Shema.kicad_sch]
2024-10-05 Delete ESP32-2432S028-b.jpg
    obsolete
2024-10-05 modification shema kicad
    [BertheVarioTac-Shema.kicad_sch]
2024-10-05 modification conditions en vol
    [BertheVarioTac-Shema.kicad_sch]
2024-10-06 essai pcb
    [BertheVarioTac-Shema.kicad_pcb, BertheVarioTac-Shema.kicad_sch]
2024-10-06 modification pcb
    [BertheVarioTac-Shema.kicad_pcb, BertheVarioTac-Shema.kicad_sch]
2024-10-07 essai gerber
    [BertheVarioTac-Shema-B_Cu.gbr, BertheVarioTac-Shema-B_Mask.gbr, BertheVarioTac-Shema-B_Paste.gbr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]
2024-10-07 pcb BMP180 a tester
2024-10-07 pcb BMP180/MS5611 a tester
    [BertheVarioTac-Shema-B_Cu.gbr, BertheVarioTac-Shema-B_Mask.gbr, BertheVarioTac-Shema-B_Paste.gbr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]
2024-10-07 Delete pcb.jpg
    pcb error
2024-10-07 Delete pcb-b.png
    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
2024-10-07 photo pcb io
2024-10-08 modif pcb
    [BertheVarioTac-Shema-B_Cu.gbr, BertheVarioTac-Shema-B_Mask.gbr, BertheVarioTac-Shema-B_Paste.gbr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]
2024-10-09 purge des boutons
2024-10-09 R sda scl pcb
    [BertheVarioTac-Shema-B_Cu.gbr, BertheVarioTac-Shema-B_Mask.gbr, BertheVarioTac-Shema-B_Paste.gbr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]
2024-10-09 fabricant pcb
2024-10-10 Delete pcb-jlpcb directory
    changement de nom
2024-10-10 reorganisation dossier
    [BertheVarioTac-Shema-B_Cu.gbr, BertheVarioTac-Shema-B_Mask.gbr, BertheVarioTac-Shema-B_Paste.gbr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]
2024-10-25 modif pcb batterie
    [BertheVarioTac-Shema-B_Cu.gbr, BertheVarioTac-Shema-B_Mask.gbr, BertheVarioTac-Shema-B_Paste.gbr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]
2024-10-25 batterie 4000mah 124065
2024-10-30 vbat max 4.3v
2024-11-01 bug ecran/ carte sd
    [CGlobalVar.cpp, CGps.cpp, CSoundSvr.cpp]
2024-11-21 batterie 4000mah
2024-11-28 nuage de points
2024-12-01 calcul de zone
2025-01-29 mise a jour plateform
2025-02-06 penetration zone 2hz
2025-02-07 bug alarme frontiere zone
    [WifiFileMgr.cpp, main.cpp]
2025-03-02 fichiers de zone
